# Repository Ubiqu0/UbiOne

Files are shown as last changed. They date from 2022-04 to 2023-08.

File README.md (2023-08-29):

# UbiOne

* [Introduction](https://github.com/Ubiqu0/UbiOne/#introduction)<br>
* [Upload sketchs](https://github.com/Ubiqu0/UbiOne/#upload-sketchs)<br>
  * [DFU](https://github.com/Ubiqu0/UbiOne/#dfu)<br>
  * [SWD](https://github.com/Ubiqu0/UbiOne/#swd)<br>
  * [Serial](https://github.com/Ubiqu0/UbiOne/#serial)<br>
* [Pinout](https://github.com/Ubiqu0/UbiOne/#pinout)<br>
  * [RPI](https://github.com/Ubiqu0/UbiOne/#rpi)<br>
  * [mPCIe](https://github.com/Ubiqu0/UbiOne/#mpcie)<br>
  * [I2S Microphone](https://github.com/Ubiqu0/UbiOne/#i2s-microphone)<br>
  * [Buzzer](https://github.com/Ubiqu0/UbiOne/#buzzer)<br>
  * [IMU and Pressure sensor](https://github.com/Ubiqu0/UbiOne/#imu-and-pressure-sensor)<br>

# Introduction

**UbiOne** is a Raspberry Pi HAT that combines an **STM32F411**, a set of **sensors**, and a **Mini-PCIe socket** to provide **LTE** connectivity to your RPI (through USB and via an LTE card).

It includes an IMU (**BMI270**), a pressure sensor (**DPS310**), an I2S microphone (**SPH0645**), a magnetometer (**QMC5883L**) and a small passive buzzer (**KLJ-4020**).

Furthermore, it manages the RPI power supply, which means you can completely shutdown the RPI and have a **true long-term sleep mode**.

**UbiOne** was designed having in mind the use of [ubiquo.net](https://ubiquo.net), a web application that allows you to control your DIY bot remotely via web browser (currently as a demo only).

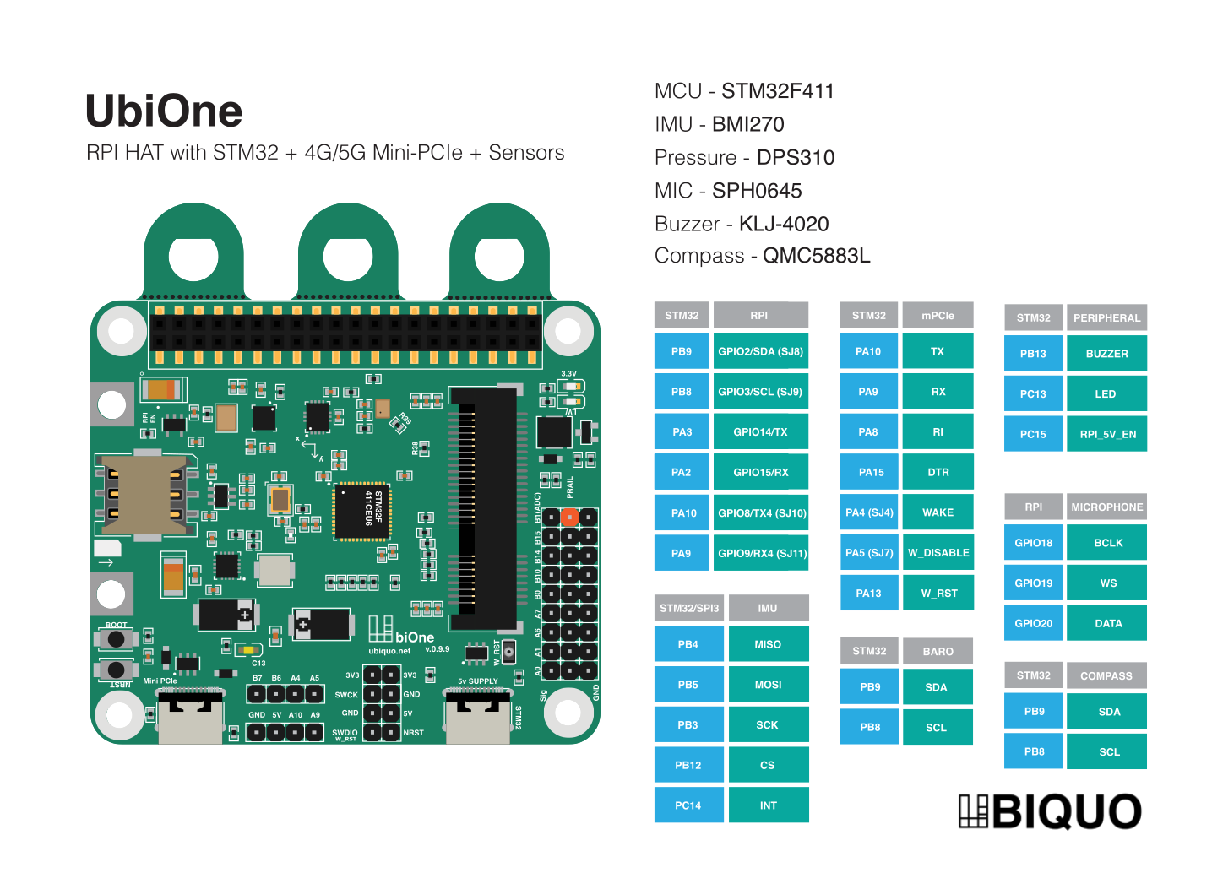
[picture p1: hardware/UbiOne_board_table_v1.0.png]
UbiOne_v.9.8


**IMPORTANT:** **UbiOne** is not yet in production! I have a working tested **prototype**, and I plan to start crowdfunding (e.g., Indiegogo) to fund the production. If you are interested, please fill out this [form](https://forms.gle/ZSxchesgbg77n8198) with your contact, and I will notify you about the campaign.  

UbiOne  | UbiOne + RPI  | UbiOne + LTE + RPI + Camera |    
:------:|:------------: |:---------------------------: |
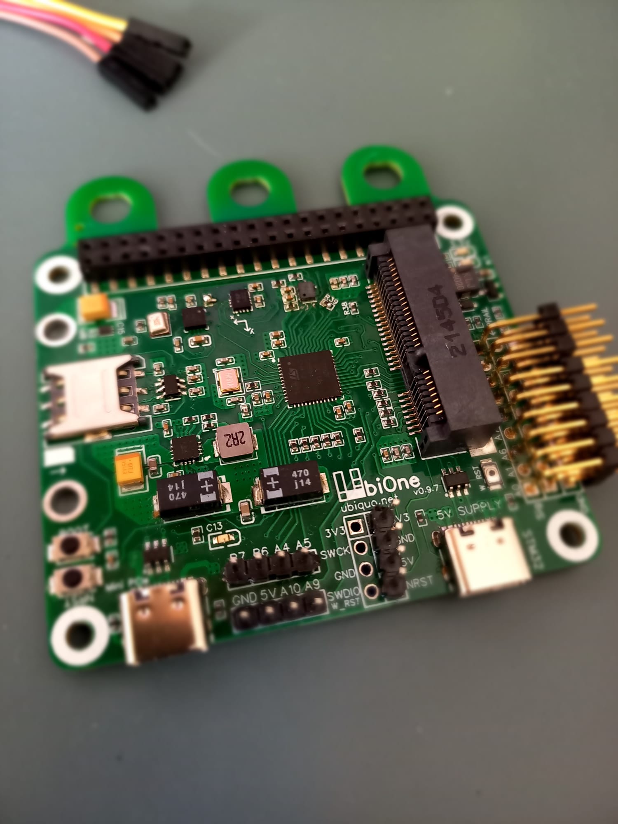
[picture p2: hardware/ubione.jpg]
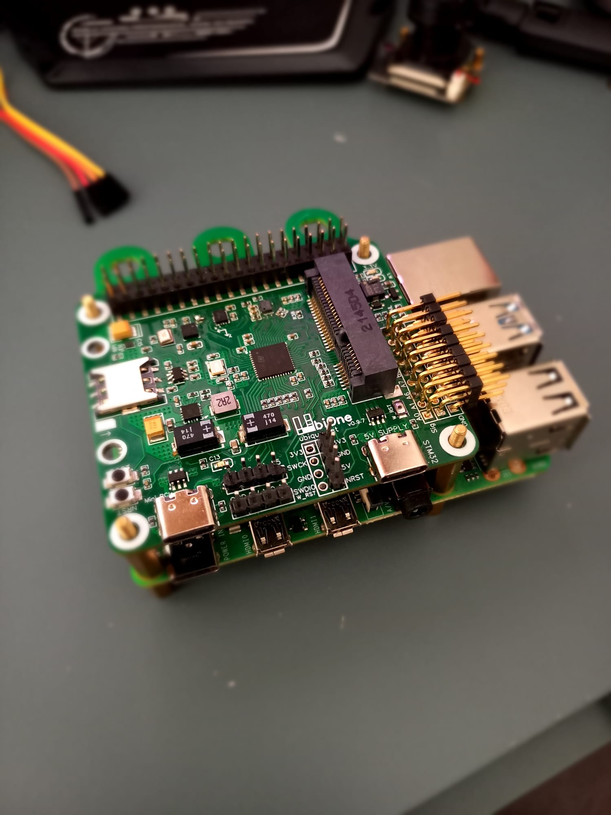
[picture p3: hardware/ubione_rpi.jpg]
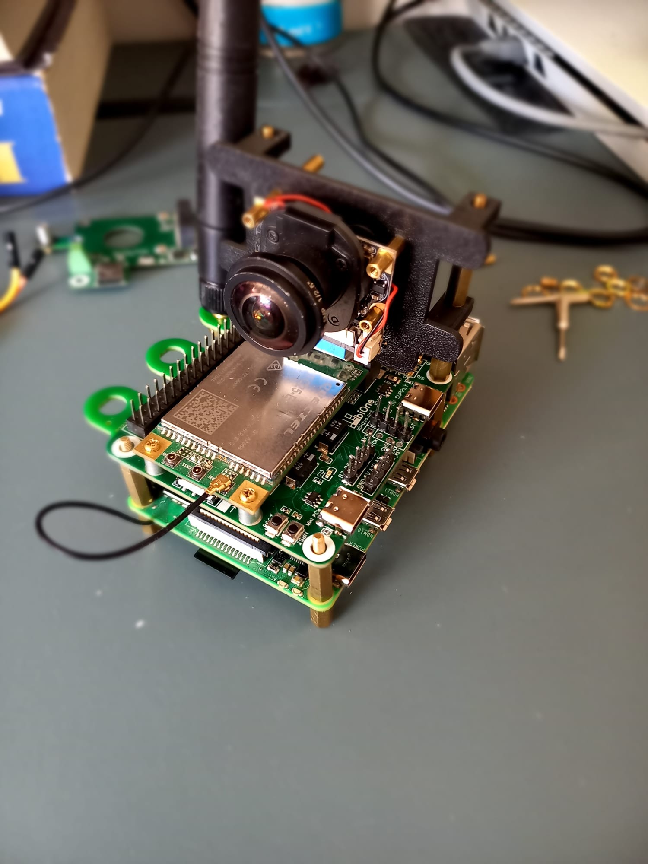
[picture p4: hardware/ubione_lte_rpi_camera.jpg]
 |  |  |

------

# Geting Started

You can use Arduino IDE to program and upload sketchs using [Arduino Core for STM32](https://github.com/stm32duino/Arduino_Core_STM32). You can follow these [steps](https://github.com/stm32duino/wiki/wiki/Getting-Started) to install the STM32 libraries or, very shortly:

- Open Arduino "**Preferences**" and add the following link to "**Additional Boards Manager URLs**":
```
https://github.com/stm32duino/BoardManagerFiles/raw/main/package_stmicroelectronics_index.json
```
1. Go to "**Tools > Board > Board Manager**" and search for "**STM32**"
2. Install the package "**STM32 MCU based boards**"
3. Install [STM32CubeProgrammer](https://www.st.com/en/development-tools/stm32cubeprog.html)

Select the STM32 board type and respective configuration:

1. Go to "**Tools > Board > STM32 Boards groups > Generic STM32F4 series**"
2. Select the board part number "**Tools > Board > Board part number**" and select "**Generic F411CEUx**"
3. Enable serial to be able to print to the Serial Monitor: "**Tools > U(S)ART support: Enabled (generical 'Serial')**"
4. Enable "**USB support (if available): CDC (generical 'Serial'...)**"

In the end, you should have the following configuration:



------

# Upload sketchs

You can upload sketches from three different ways: **DFU**, **SWD**, or **Serial**.

## DFU

To compile and upload in **DFU mode** go to "**Tools > Upload method > STM32CubeProgrammer (DFU)**".

Now, follow the next steps:

  1. Connect your PC to **UbiOne** through the <ins>STM32 USB-C port</ins>.
  2. Put the STM32 MCU in **programming mode** by:
      1. pressing and holding **BOOT**
      2. press and release **NRST**
      3. release **BOOT**
  3. Arduino IDE is now ready to compile and upload (click upload in Arduino IDE)

## SWD

To compile and upload in **SWD mode** go to "**Tools > Upload method > STM32CubeProgrammer (SWD)**". To program via SWD you need an ST-LINK/V2, that can be the [official](https://www.st.com/content/st_com/en/products/development-tools/hardware-development-tools/hardware-development-tools-for-stm32/st-link-v2.html) or a smaller (and cheaper) version like this one:



When uploading via SWD, you don't need to put the STM32 in any particular mode. All you need is to connect the pins:

  - **GND**
  - **SWDIO**
  - **SWCLK**
  - **3.3V** (optional: you should connect only in case you are powering the UbiOne through the ST-LINK/V2)

## Serial

A third option is to program through Serial, using, for example, an FTDI USB UART converter like this one:



To compile and upload in **UART mode** go to "**Tools > Upload method > STM32CubeProgrammer (Serial)**". 

Next, follow the steps:
  1. Connect the pins:
     1. RX to A9
     2. TX to A10
     3. GND to GND
     4. 3.3V to 3.3V or 5V to 5V (it depends on the option you have selected in the FTDI converter).
  2. Put the STM32 MCU in **programming mode** by
      1. pressing and holding **BOOT**
      2. press and release **NRST**
      3. release **BOOT**
  3 Arduino IDE is now ready to compile and upload (click upload in Arduino IDE)

---
# Pinout

The following pins are available through the pin headers: **PB7, PB6, PA4, PA5, PA10, PA9, PA0, PA1, PA6, PA7, PB0, PB10, B13, PB15, and PB1**. You can find more details about each in the [datasheet](https://www.st.com/en/microcontrollers-microprocessors/stm32f411ce.html). You can also use [STM32CubeMX](https://www.st.com/en/development-tools/stm32cubemx.html) (search for STM32F411CEU).

## RPI

UbiOne can be interfaced with the 40-pin RPI header.

| STM32 |  RPI GPIO | RPI Pin | Function | 
| :-----: | :-----: |  :-----: | :-----: |
| PB9  | GPIO2 (SJ1) | 3 | I2C_SDA | 
| PB8  | GPIO3 (SJ2) | 5 | I2C_SCL | 
| PA3  | GPIO14  | 8 | UART2_RX |
| PA2  | GPIO15  | 10 | UART2_TX |
| PA10  | GPIO8 (SJ10)  | 24 | UART4_TX |
| PA9  | GPIO9 (SJ11)  | 21 | UART4_RX |

SJ* means a solder jumper.  By default, they are not connected, and therefore you need to solder it in case of use.

As the table shows, **UbiOne** can communicate directly with the RPI via UART pins (GPIO14 and GPIO15 or GPIO8 and GPIO9). Please note that to do so, you need to first to configure the RPI:

1. Go to the RPI system configuration menu by typing ```sudo raspi-config``` in a terminal.
2. Go to "**Interface Options > Serial Port**"
3. Select "**No**" to the first question (related to login)
4. Select "**Yes**" to the second question to enable serial

5. If you want to use RPI's UART4 (RPI4 makes available aditional UART ports) available at GPIO8 and GPIO9, add ```dtoverlay=uart4``` to ```boot/config.txt``` file.
## mPCIe

**UbiOne** can fit a Mini-PCIe card based on the pinout of a [Quectel LTE EC25 Mini PCIe](https://www.quectel.com/product/lte-ec25-mini-pcie-series). In case you use any other card, you should pay attention if it respects the same pin configuration.

| STM32 |  mPCIe function | mPCIe pin |
| :-----: | :-----: |  :-----: |
| PA10 | TX | 13 |
| PA9  | RX | 11 |
| PA8 | RI | 17 |
| PA15 | DTR | 31 |
| PA4 (SJ3) | WAKE | 1 |
| PA5 (SJ4) | W_DISABLE | 20 |
| PA13 | W_RST | 22 | 

If you need to use WAKE and W_DISABLE functions you must solder **SJ3** and **SJ4**. 

You can reset the LTE module by pressing the **W_RST** or drive **PA13** pin low between 100 and 500 ms. Also, please note that PA13 is also SWDIO pin, which means you should not have the LTE module connected if uploading the STM32 via SWD. 

## I2S Microphone

**UbiOne** incorporates an I2S microphone. The setup is the same as the [I2S MEM Microphone board from Adafruit](https://learn.adafruit.com/adafruit-i2s-mems-microphone-breakout/overview), where the mic is directly connected to RPI through GPIO pins GPIO18, GPIO19, and GPIO20. To use with the RPI just follow the [Adafruit guide](https://learn.adafruit.com/adafruit-i2s-mems-microphone-breakout/raspberry-pi-wiring-test).

**NOTE**: for some reason, the file `~/.asoundrc` keeps getting deleted (related to [this](https://forums.raspberrypi.com/viewtopic.php?t=295008) issue). So if you notice any problem with the microphone, please first check if the file is there.

| RPI |  Microphone | 
| :-----: | :-----: |
| GPIO18 | BCLK |  
| GPIO19  | WS | 
| GPIO20 | DATA |

## Buzzer

Since **UbiOne** has a microphone, it would be nice to have a speaker. However, we think we can agree it would be pretty challenging to add a speaker to this little board. Even so, we added a small buzzer to pin **PB13** that allows playing a simple buzz and some nice tunes.  Try, for example, [this](https://github.com/Ubiqu0/UbiOne/blob/main/examples/buzzer/very_nice_tune.ino) one! :wink:

## IMU 

The IMU sensor (ICM-20689) is by default connected to the STM32F411 through an SPI connection:

| IMU |  STM32 | 
| :-----: | :-----: |
| MISO | PB4 |  
| MOSI | PB5 |  
| SCK  | PB3 | 
| CS | PB12 |
| INT | PC14 |

If you want to use I2C instead, you must solder **SJ5**, **SJ6** and **SJ7**. You should also remove resistors **R38** and **R39** to release SCK and MOSI connections from the STM32F411. In this scenario we have the following connections:

| IMU |  STM32 | 
| :-----: | :-----: |
| SDA | PB9 |  
| SCL | PB8 |  

You can also  make readings from the RPI using its I2C port. For such scenario you must use RPI I2C pins **GPIO2** and **GPIO3**, and solder **SJ1**, **SJ2**. If you ask why it isn't everything connected, the RPI can only behave as master and does not support I2C multi-master. When connected, you lose the possibility of using the STM32 as a master in an I2C communication.

## Pressure sensor

The pressure sensor (DPS310) is permantly connected through a I2C connection. Again, if you want to read from the RPI you must solder **SJ1**, **SJ2**.

| DPS310 |  STM32 | 
| :-----: | :-----: |
| SDA | PB9 |  
| SCL | PB8 |

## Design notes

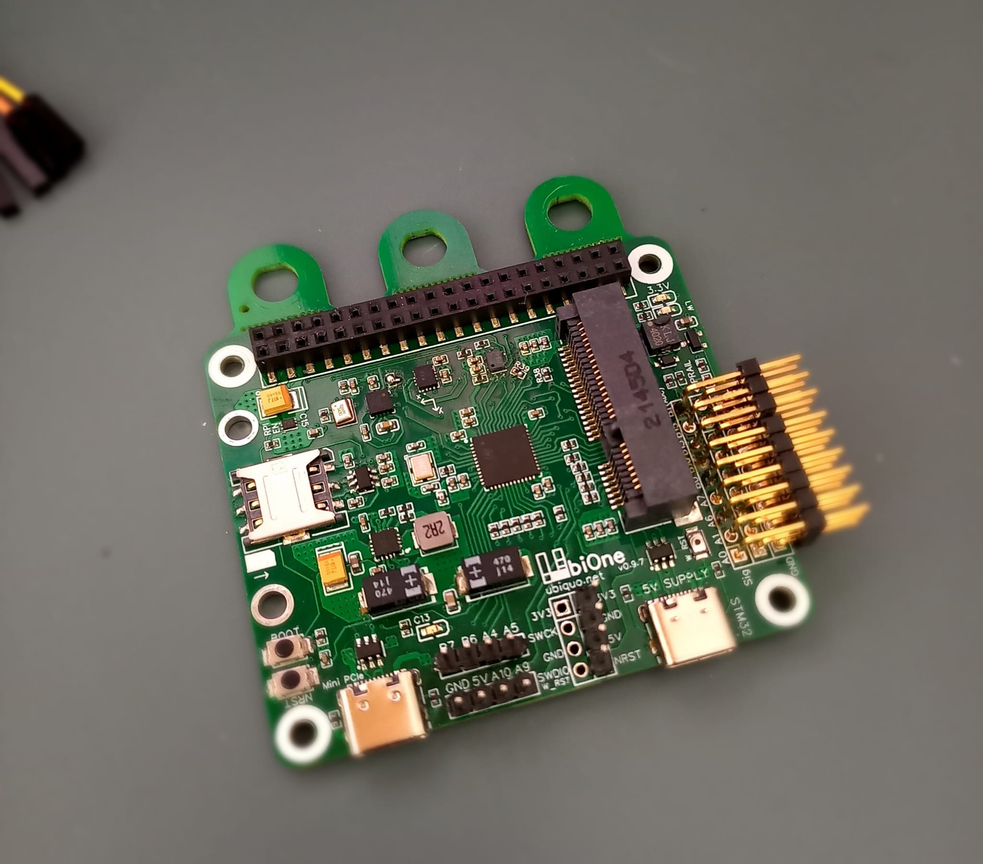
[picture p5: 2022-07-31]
hardware/ubione.jpeg

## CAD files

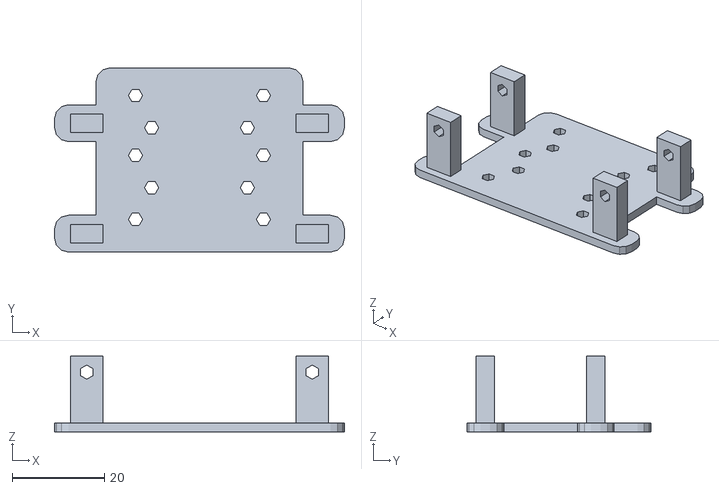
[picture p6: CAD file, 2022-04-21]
examples/rover/3DParts/camera_support.stl
63.0 x 40.0 x 16.5

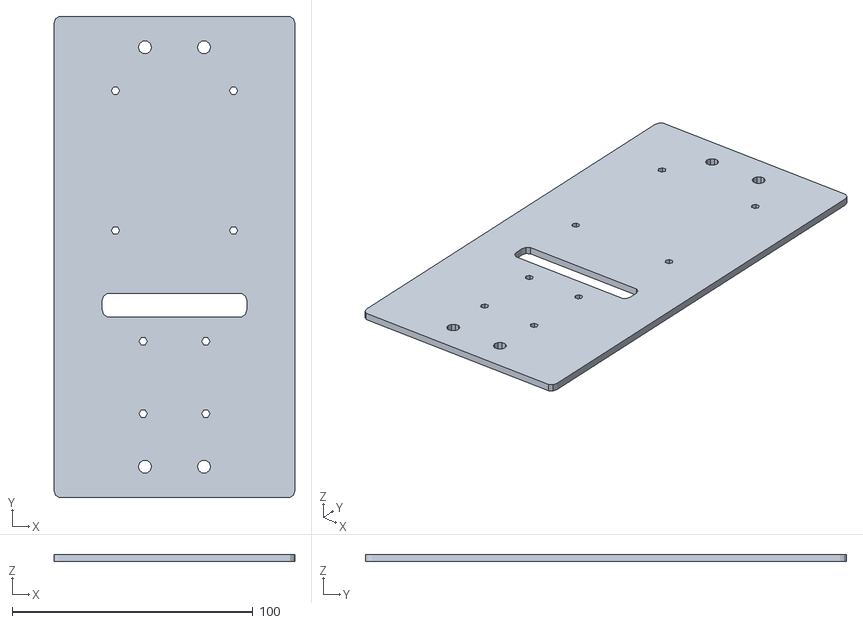
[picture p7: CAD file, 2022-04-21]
examples/rover/3DParts/supporting_base.stl
100.0 x 199.7 x 3.00

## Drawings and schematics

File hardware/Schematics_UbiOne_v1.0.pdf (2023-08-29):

# USB PCIe

# STM32F411CEU6

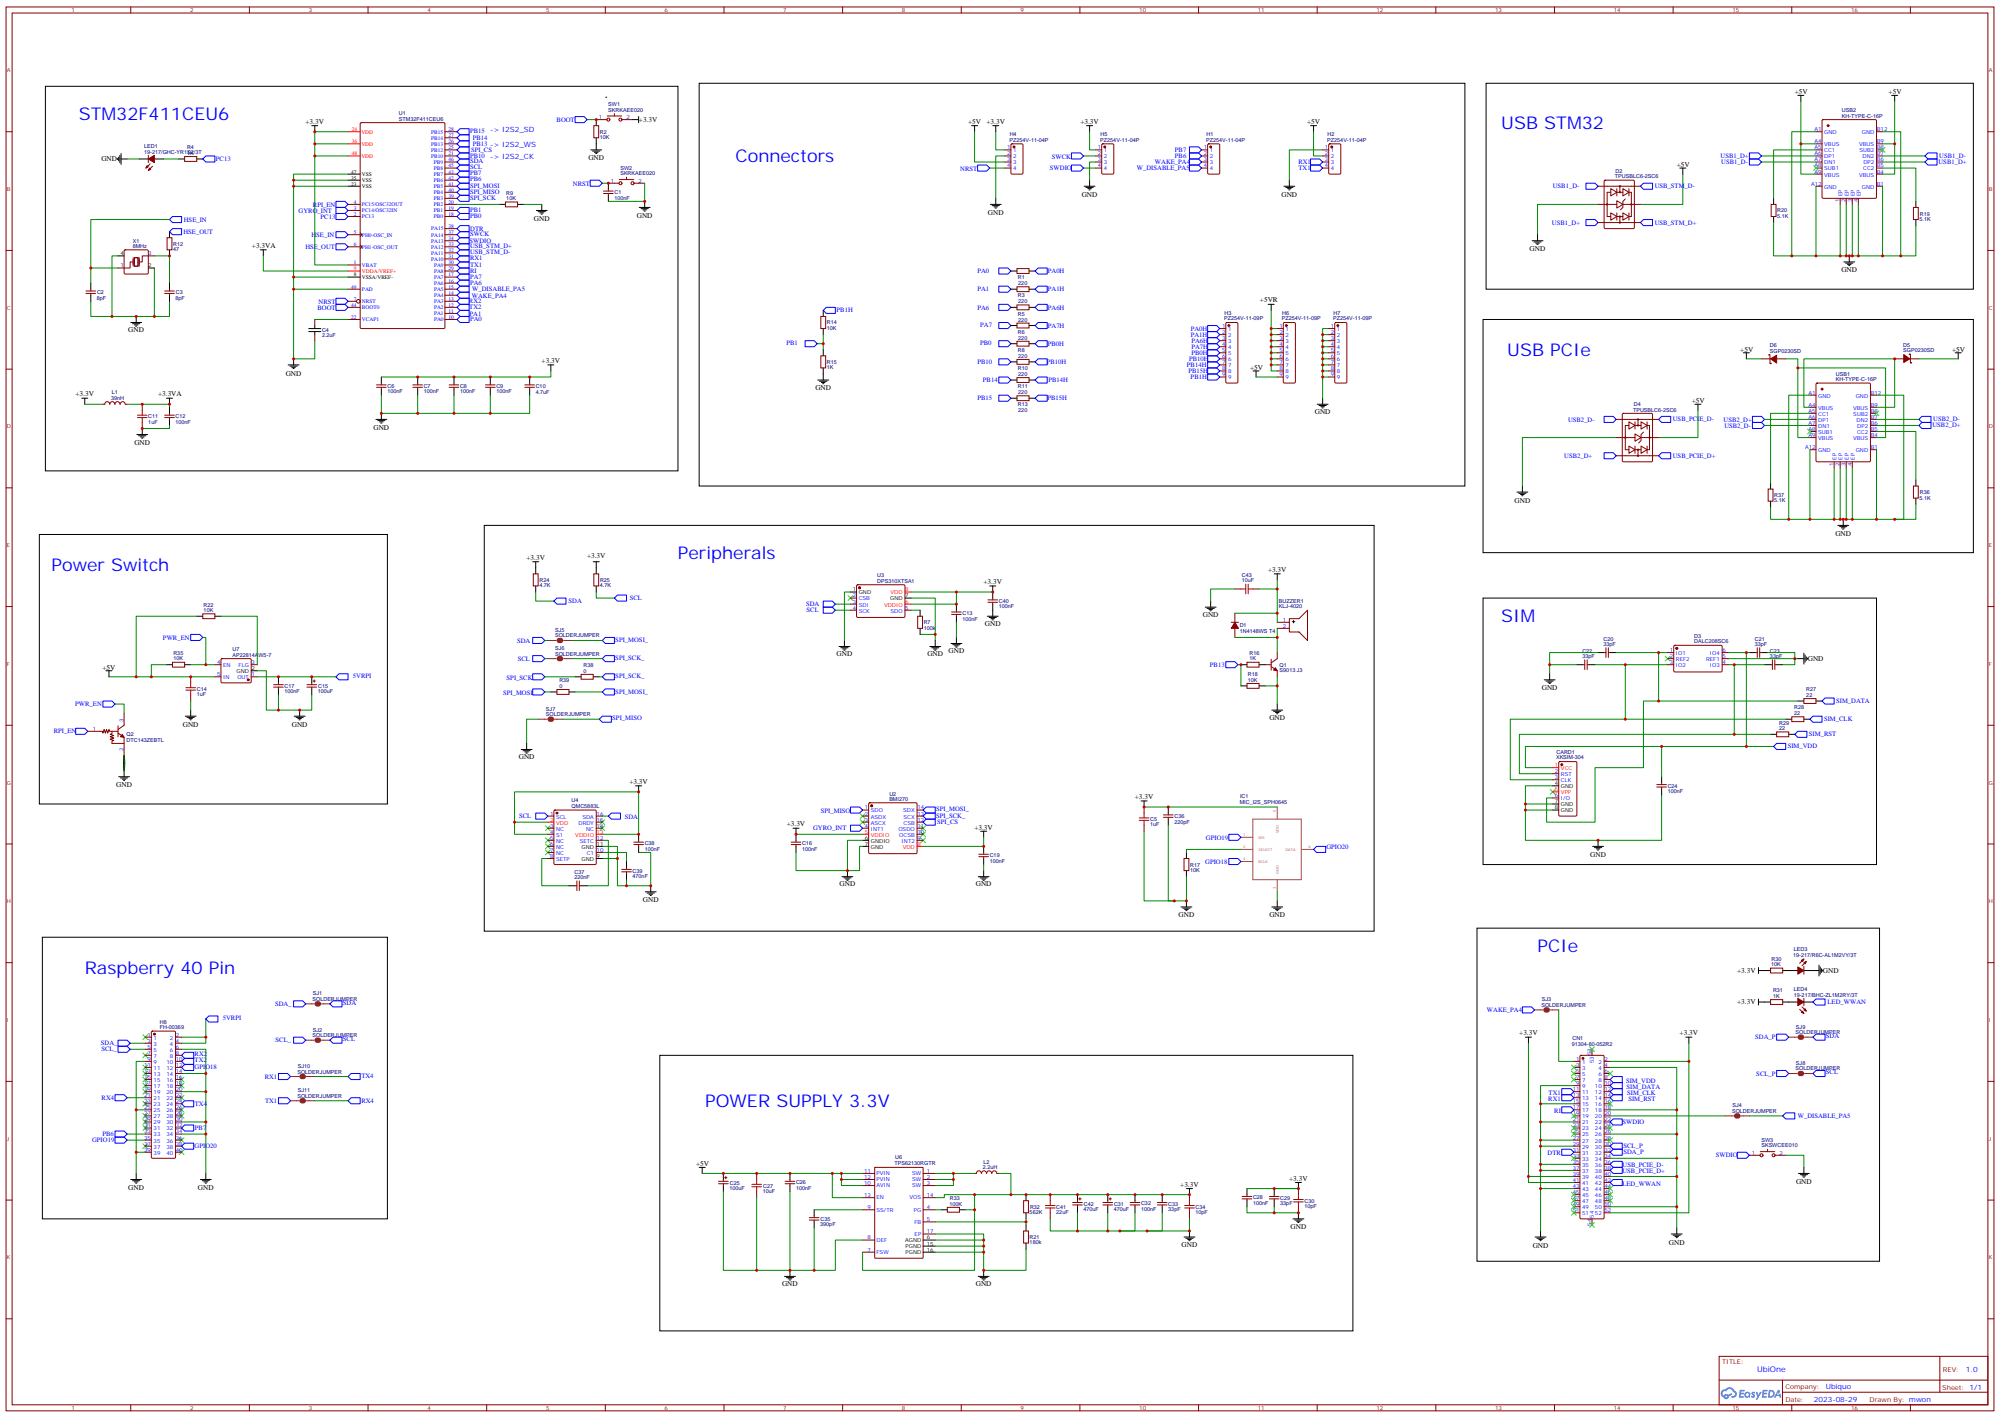
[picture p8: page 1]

QMC5883L
C1 10 GND 11 SETC 12 VDDIO 13 NC 14 DRDY 15 SDA 16

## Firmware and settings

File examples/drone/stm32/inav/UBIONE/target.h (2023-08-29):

/*
 * This file is part of Cleanflight.
 *
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
 * You should have received a copy of the GNU General Public License
 * along with Cleanflight.  If not, see <http://www.gnu.org/licenses/>.
 */

#pragma once

#define TARGET_BOARD_IDENTIFIER "UB1"
#define USBD_PRODUCT_STRING     "UBIONE"

//#define HSE_MZ 25

USE_GPS
USE_GPS_PROTO_UBLOX
USE_GPS_PROTO_NMEA
USE_GPS_PROTO_MSP

#define LED0                    PC13

#define BEEPER                  PB13
#define BEEPER_INVERTED
#define BEEPER_PWM_HZ             2000

// *************** SPI **********************

#define USE_SPI
#define USE_SPI_DEVICE_3
#define SPI3_SCK_PIN               PB3
#define SPI3_MISO_PIN   	   PB4
#define SPI3_MOSI_PIN   	   PB5
#define SPI3_NSS_PIN            PB12

#define GYRO_1_SPI_INSTANCE    SPI3
#define GYRO_1_CS_PIN          SPI3_NSS_PIN
#define GYRO_1_ALIGN      CW0_DEG

#define USE_EXTI
#define USE_GYRO_EXTI
#define GYRO_1_EXTI_PIN         PC14
#define USE_MPU_DATA_READY_SIGNAL
#define ENSURE_MPU_DATA_READY_IS_LOW


#define USE_IMU_BMI270
#define BMI270_CS_PIN         SPI3_NSS_PIN
#define BMI270_SPI_BUS        BUS_SPI3
#define IMU_BMI270_ALIGN      CW0_DEG

// *************** Baro & Mag *****************************

#define USE_I2C
#define USE_I2C_DEVICE_1
#define I2C1_SCL                PB8
#define I2C1_SDA                PB9

#define USE_BARO
#define BARO_I2C_BUS		    BUS_I2C1
#define USE_BARO_DPS310

#define USE_MAG
#define MAG_I2C_BUS             BUS_I2C1
#define USE_MAG_QMC5883


// *************** UART *****************************

#define USE_VCP

#define USE_UART1
#define UART1_TX_PIN            PA9
#define UART1_RX_PIN            PA10

#define USE_UART2
#define UART2_RX_PIN            PA3
#define UART2_TX_PIN            PA2

#define USE_SOFTSERIAL1
#define SOFTSERIAL_1_TX_PIN     PB6
#define SOFTSERIAL_1_RX_PIN     PB7

#define USE_SOFTSERIAL2
#define SOFTSERIAL_2_TX_PIN     PA8
#define SOFTSERIAL_2_RX_PIN     PA15


#define DEFAULT_RX_TYPE         RX_TYPE_SERIAL
#define SERIALRX_PROVIDER       SERIALRX_SBUS
#define SERIALRX_UART           SERIAL_PORT_USART1

#define SERIAL_PORT_COUNT       5       // VCP, USART1,USART2,SS1,SS2

// *************** ADC *****************************

#define USE_ADC
#define ADC_INSTANCE                    ADC1
#define ADC_CHANNEL_1_PIN               PB1
#define VBAT_ADC_CHANNEL                ADC_CHN_1

// *************** RPI PWR ***************************
#define USE_PINIO
#define USE_PINIOBOX
#define PINIO1_PIN                  PC15 // RPI EN

// ***************  OTHERS *************************
#define DEFAULT_FEATURES                ( FEATURE_VBAT | FEATURE_SOFTSERIAL)

#define USE_DSHOT

#define TARGET_IO_PORTA         0xffff
#define TARGET_IO_PORTB         0xffff
#define TARGET_IO_PORTC         0xffff
#define TARGET_IO_PORTD        (BIT(2))

#define MAX_PWM_OUTPUT_PORTS       6

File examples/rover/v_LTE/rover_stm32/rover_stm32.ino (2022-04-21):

#include <Servo.h>
#define DEBUG Serial

//HardwareSerial DEBUG(USART2); //A2(TX) and A3(RX)
HardwareSerial RPI(USART2);

const byte MAX_REC_BYTES = 12;      // Maximum received bytes allowed
int receiveBuffer[MAX_REC_BYTES];
bool serialRead = true;
int maxWithoutSerial = 200;
unsigned long lastSerial = 0;
const byte NMOTORS = 2;
unsigned long blink_timer = millis();


Servo servo[NMOTORS]; // 1 for the main DC motor, 1 for the left right servo and 2 for the camera gimbal

void setup() {

  /* Begin serial communication for remote control */
  DEBUG.begin(115200);                                          //Set the serial output to 57600 kbps.
  RPI.begin(115200);
  pinMode(PC13, OUTPUT);
  DEBUG.println("Ready");

}

void loop() {

  int currentMillis = millis();
  if (currentMillis - lastSerial >= maxWithoutSerial){
    for (int i = 0;i < NMOTORS;i++){
      if (servo[i].attached()){
        servo[i].writeMicroseconds(1500);
      }
    }
  }
  /* Receive the remote controller's commands */
  if (RPI.available() >= MAX_REC_BYTES && serialRead){
    receiveControl();
  }
  blinkLED();

  delay(10);
}

/**
 * LLED blink to make sure the main loop is running and not stuck
 */
void blinkLED() {
  if(millis()-blink_timer > 1000) {
    int level = digitalRead(PC13);
    digitalWrite(PC13, !level);
    blink_timer = millis();
    DEBUG.println("DEBUG OK");
  }
}

void receiveControl() {
  serialRead = false;

  int i = 0;
  for (int i=0;i<MAX_REC_BYTES;i++){
    receiveBuffer[i] = RPI.read();
  }
  while(RPI.available()){
    RPI.read();
  }

 for(i = 0;i<NMOTORS+1;i++){
  int pos = i;
  int cmds = receiveBuffer[i*4];
  int pin = receiveBuffer[i*4+1];
  int hsb = receiveBuffer[i*4+2];
  int lsb = receiveBuffer[i*4+3];
  int ms = hsb*256 + lsb;

  DEBUG.print(pos);
  DEBUG.print(" |" );
  DEBUG.print(cmds);
  DEBUG.print(" |" );
  DEBUG.print(pin);
  DEBUG.print(" |" );
  DEBUG.print(hsb);
  DEBUG.print(" |" );
  DEBUG.print(lsb);
  DEBUG.print(" |" );
  DEBUG.println(ms);



  switch (cmds) {
    case 10:
      servo[pos].attach(pin,1000,2000,1500);
      break;
    case 15:
      servo[pos].writeMicroseconds(ms);
      break;
    case 20:
      servo[pos].detach();
      break;
    case 30:
      tone(pin, ms, 100);
      break;
    default:
      break;
  }

 }
 lastSerial = millis();
 serialRead = true;
}

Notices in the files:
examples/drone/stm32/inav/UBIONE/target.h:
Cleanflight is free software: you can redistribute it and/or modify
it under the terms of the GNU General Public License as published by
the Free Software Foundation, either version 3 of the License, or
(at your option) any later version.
